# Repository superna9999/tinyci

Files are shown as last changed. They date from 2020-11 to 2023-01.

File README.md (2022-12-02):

# TinyCI

General Concept:

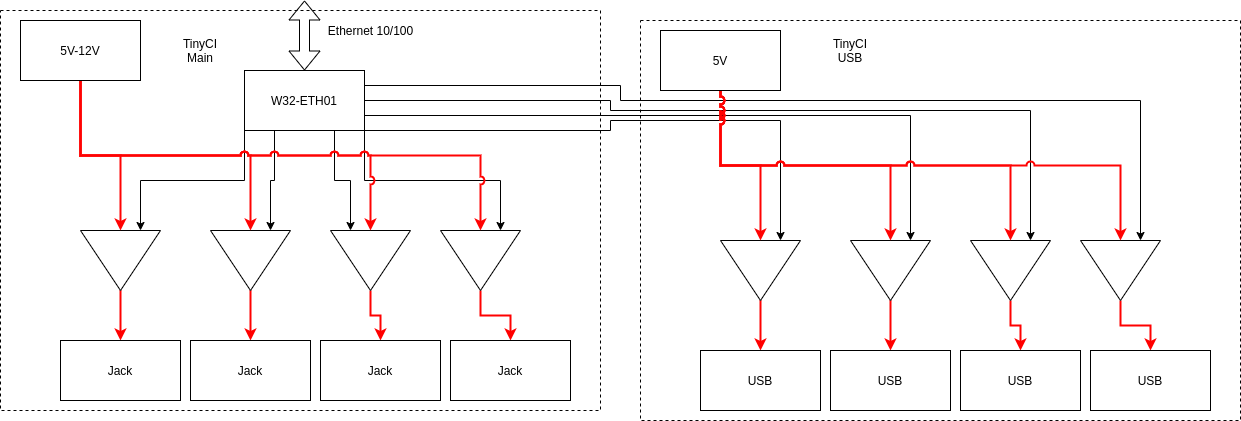
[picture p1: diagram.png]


TinyCi Main
-----------

Relay board controlled by a `W32-ETH01` module.

Input: 5V

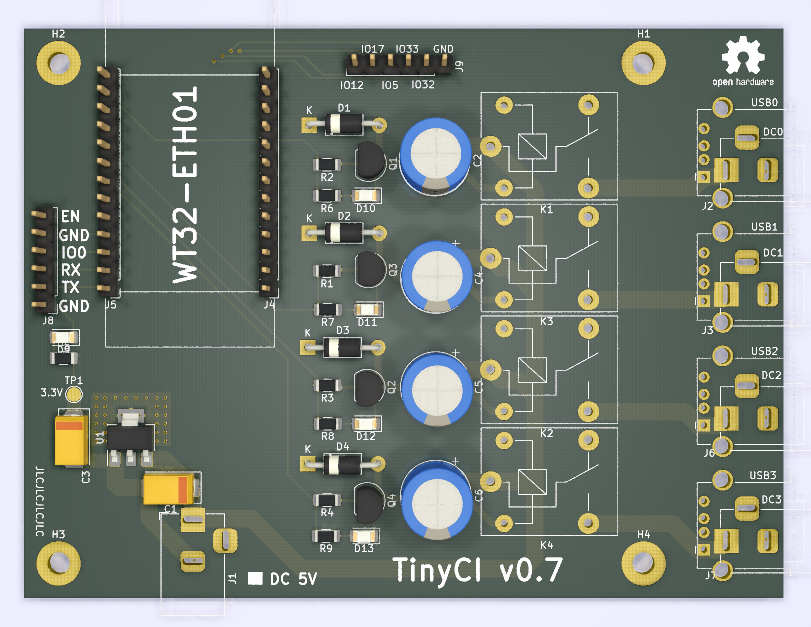
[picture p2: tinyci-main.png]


Produced:
- v0.5: x5 produced, x4 soldered, x3 used in production
- v0.7: x5 produced & used in production
- v0.8: Design done

ESP32 Firmware: see `firmware/tinyci-fw/`

Remote Relay Control script: see `firmware/tinyci-fw/tinyci-relay.py`

TinyCi USB
-----------

Secondary Relay board controlled by the `W32-ETH01` on the main board.

Input: 5V to 12V

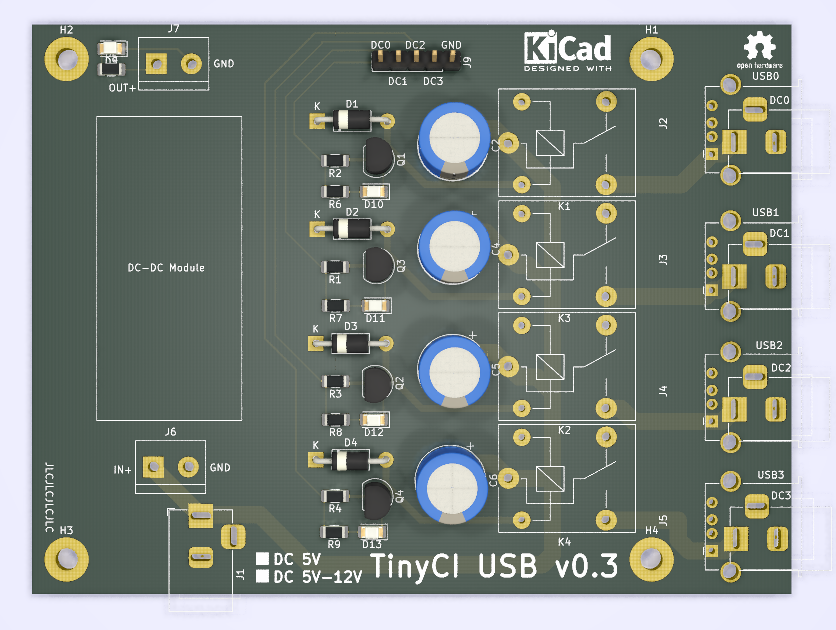
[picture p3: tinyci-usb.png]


Produced:
- v0.1: x5 produced, x3 soldered, x2 used in production
- v0.3: x5 Produced, x0 used in production

TinySerial
-----------

Quad FTDI board + breakout of all FTDI I/Os with the TinyCi form factor + holes
to hook a Pi/LaFrite/LePotato to control the FTDI + TinyCi USBs.

Input: USB

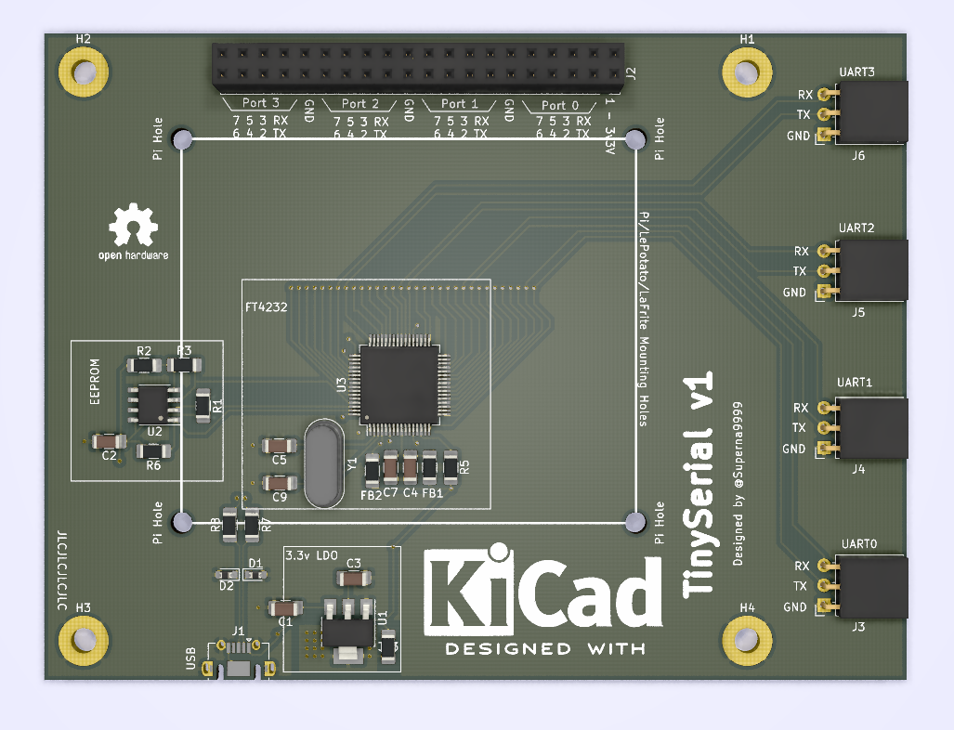
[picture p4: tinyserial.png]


Produced:
- v1: x5 Produced, failed to bringup, will be replaced with OctoSerial using CH348Q

LICENCE
-------

```
CERN OPEN HARDWARE LICENCE v1.1
```

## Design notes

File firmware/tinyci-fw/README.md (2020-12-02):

# TinyCI Relay Firmware

## Build
```
. /path/to/esp-idf/export.sh
idf.py build
```

## Ground IO0
```
idf.py flash
```

## Test
```
python2.7 tinyci-relay.py 192.168.1.12 PWR0
python2.7 tinyci-relay.py 192.168.1.12 OFF2
```

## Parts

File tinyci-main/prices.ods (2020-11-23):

Model | Unit per Cmd | Cmd Number | Total Price | Price per unit | Unit Used | Price for board | Possible num of boards | Url
BC337-25 | 50 | 1 | 1,34 € | 0,03 € | 4 | 0,11 € | 12,5 | https://fr.aliexpress.com/item/33027063943.html
SRD-03 | 5 | 5 | 4,03 € | 0,16 € | 4 | 0,64 € | 6,25 | https://fr.aliexpress.com/item/10000000543749.html
WT32-ETH01 | 1 | 3 | 22,59 € | 7,53 € | 1 | 7,53 € | 3 | https://fr.aliexpress.com/item/1005001556914151.html
AMS1117-3.3 | 10 | 1 | 1,44 € | 0,14 € | 1 | 0,14 € | 10 | https://fr.aliexpress.com/item/4001158893261.html
JACK | 10 | 2 | 2,36 € | 0,12 € | 5 | 0,59 € | 4 | https://fr.aliexpress.com/item/33005175186.html
polyfuse | 100 | 1 | 3,51 € | 0,04 € | 4 | 0,14 € | 25 | https://fr.aliexpress.com/item/32959558358.html
35V 10UF D | 10 | 1 | 1,04 € | 0,10 € | 2 | 0,21 € | 5 | https://fr.aliexpress.com/item/4000190521272.html
1N4001 | 100 | 1 | 1,64 € | 0,02 € | 8 | 0,13 € | 12,5 | https://fr.aliexpress.com/item/32829962185.html
1000uF | 50 | 1 | 3,93 € | 0,08 € | 4 | 0,31 € | 12,5 | https://fr.aliexpress.com/item/32351437821.html
PCB | 5 | 1 | 7,77 € | 1,55 € | 1 | 1,55 € | 5 | https://jlcpcb.com/
LED | 100 | 1 | 1,53 € | 0,02 € | 5 | 0,08 € | 20 | https://www.aliexpress.com/item/33049173418.html
R | 660 | 1 | 2,83 € | 0,00 € | 9 | 0,04 € | 73,3333333333333 | https://www.aliexpress.com/item/33029877427.html
 |  |  |  |  | Board Price | 11,48 €

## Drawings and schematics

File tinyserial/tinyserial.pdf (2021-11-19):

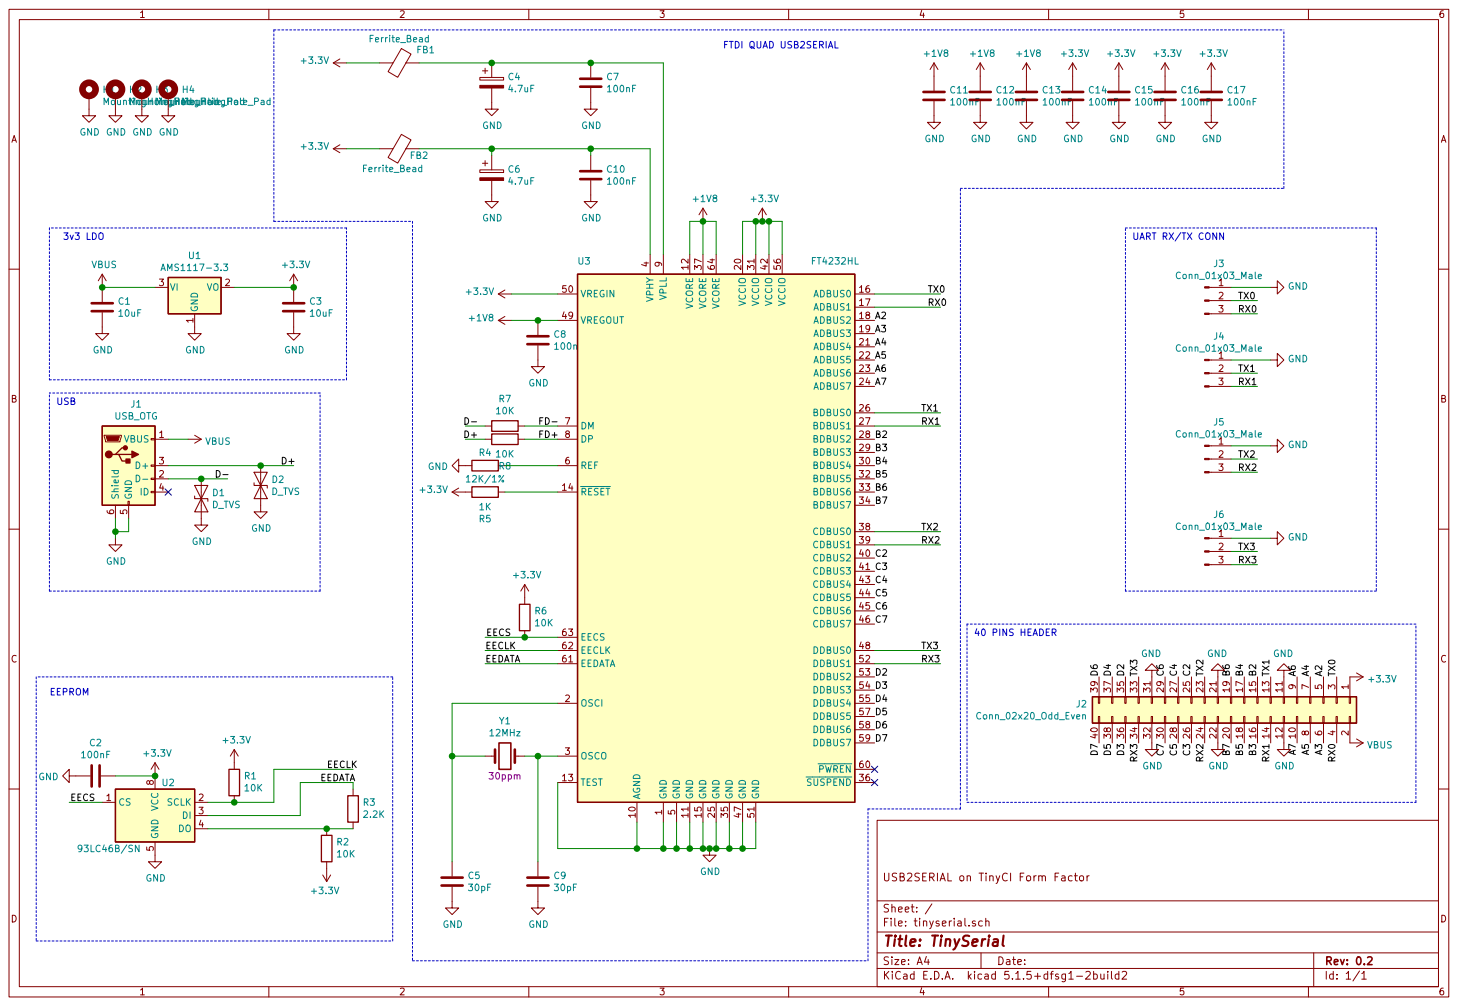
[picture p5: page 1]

5 VREGIN 50 GND 51 DDBUS1 52 DDBUS2 53 DDBUS3 54 DDBUS4 55 VCCIO 56 DDBUS5 57 DDBUS6 58 DDBUS7 59 REF 6 PWREN 60 EEDATA 61 EECLK 62 EECS 63 VCORE 64 DM 7 DP 8 VPLL U3 9FT4232HL R5

1 AGND 10 GND 11 VCORE 12 TEST 13 RESET 14 GND 15 ADBUS0 16 ADBUS1 17 ADBUS2 18 ADBUS3 19 OSCI 2 VCCIO 20 ADBUS4 21 ADBUS5 22 ADBUS6 23 ADBUS7 24 GND 25 BDBUS0 26 BDBUS1 27 BDBUS2 28 BDBUS3 29 OSCO 3 BDBUS4 30 VCCIO 31 BDBUS5 32 BDBUS6 33 BDBUS7 34 GND 35 SUSPEND 36 VCORE 37 CDBUS0 38 CDBUS1 39 VPHY

4 CDBUS2 40 CDBUS3 41 VCCIO 42 CDBUS4 43 CDBUS5 44 CDBUS6 45 CDBUS7 46 GND 47 DDBUS0 48 VREGOUT 49 GND

File: tinyserial.sch Sheet: / USB2SERIAL on TinyCI Form Factor

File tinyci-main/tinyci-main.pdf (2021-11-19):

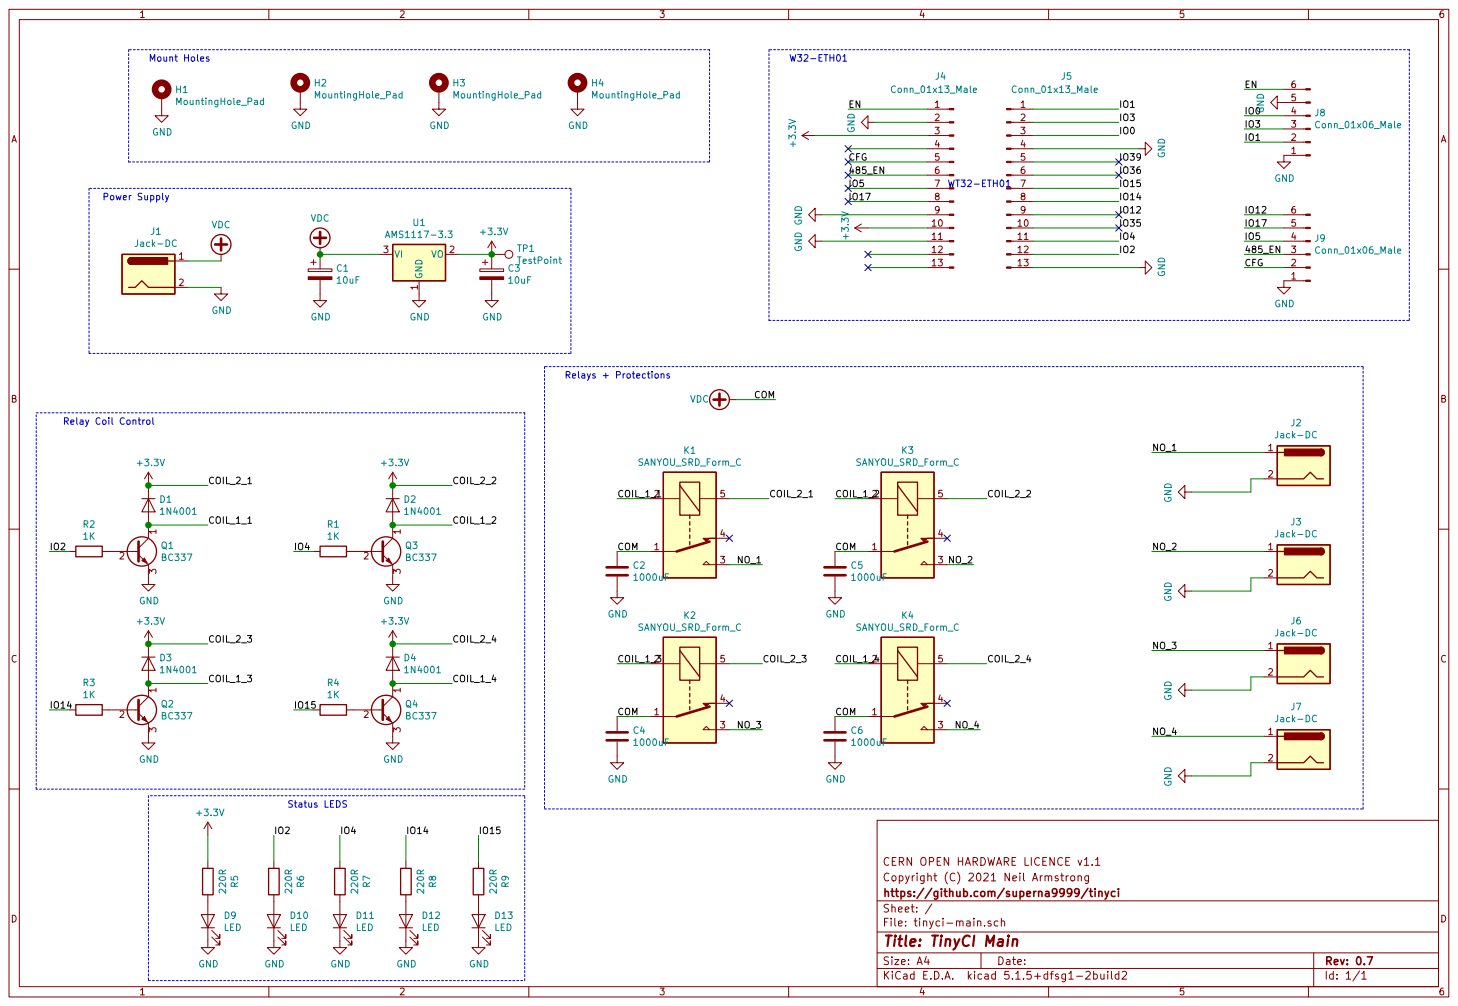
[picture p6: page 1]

Mount Holes Power Supply

Copyright (C) 2021 Neil Armstrong CERN OPEN HARDWARE LICENCE v1.1 GND
5 K2 SANYOU_SRD_Form_C

File: tinyci-main.sch Sheet: / https://github.com/superna9999/tinyci

Id: 1/1 Title: TinyCI Main

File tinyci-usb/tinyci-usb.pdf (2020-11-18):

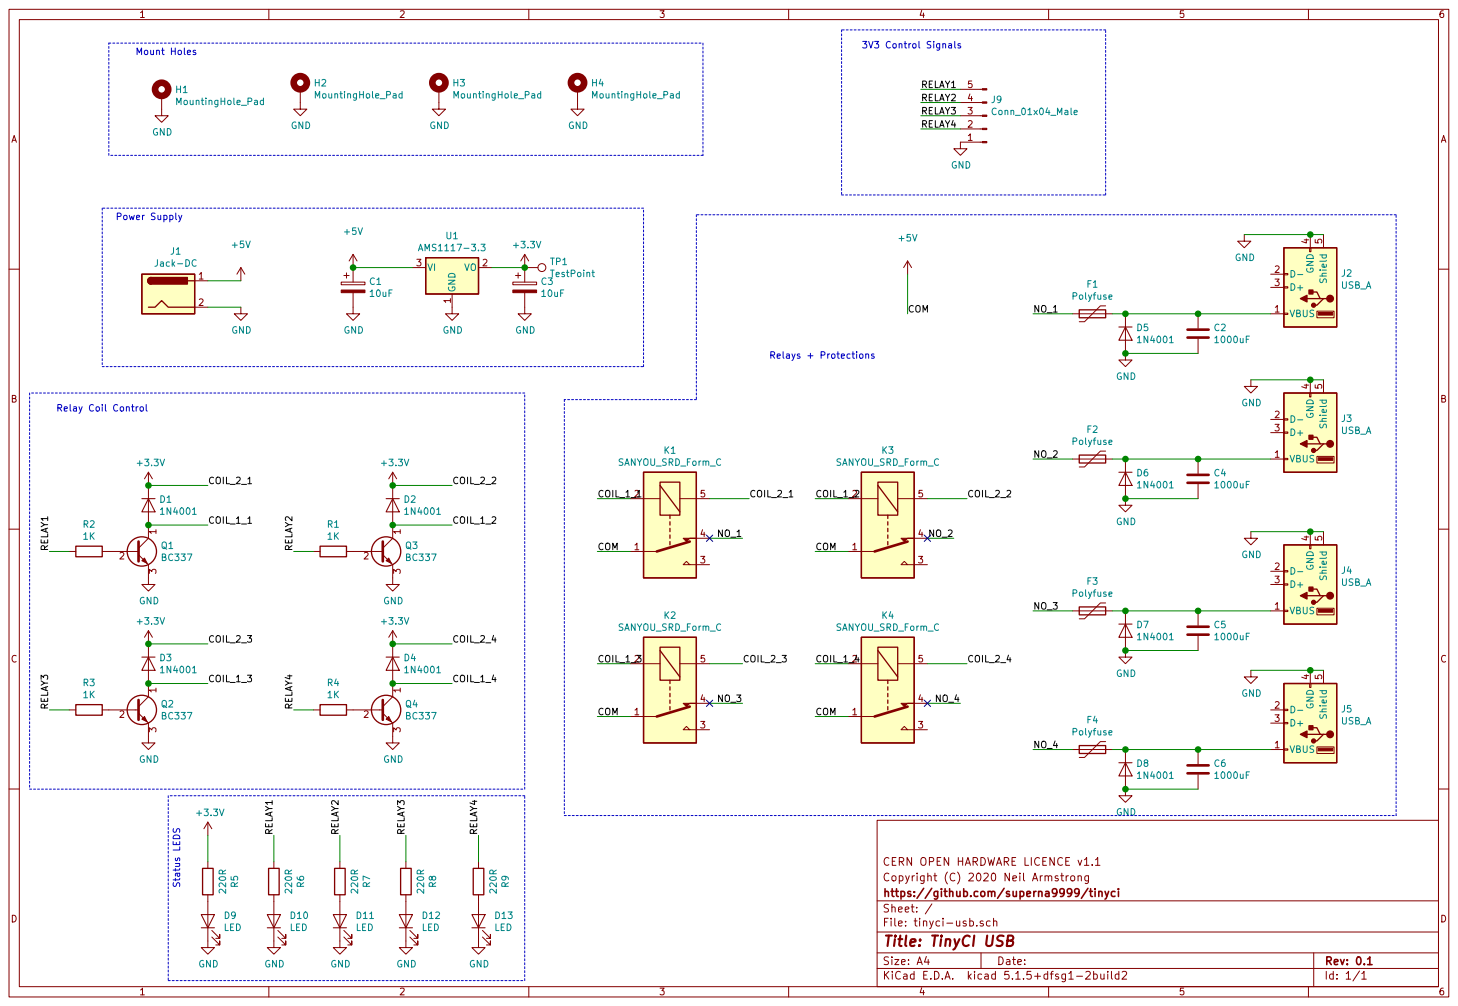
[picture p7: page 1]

3V3 Control Signals Mount Holes Power Supply

File: tinyci-usb.sch Sheet: / https://github.com/superna9999/tinyci

Id: 1/1 Title: TinyCI USB

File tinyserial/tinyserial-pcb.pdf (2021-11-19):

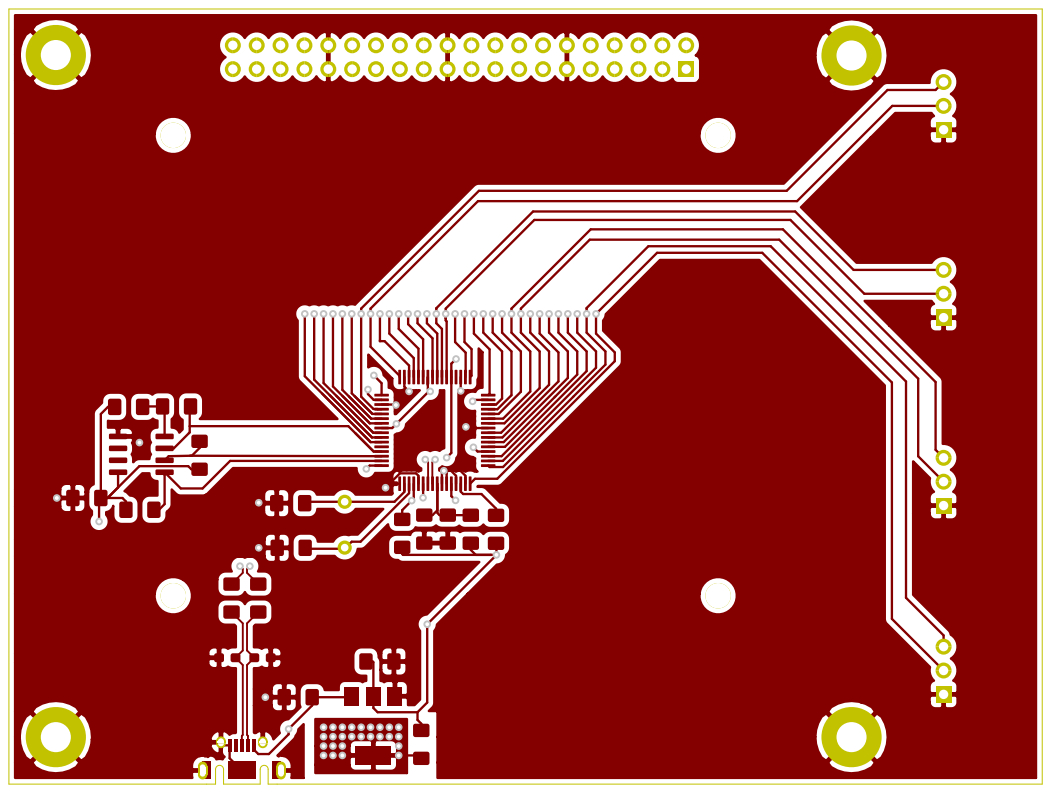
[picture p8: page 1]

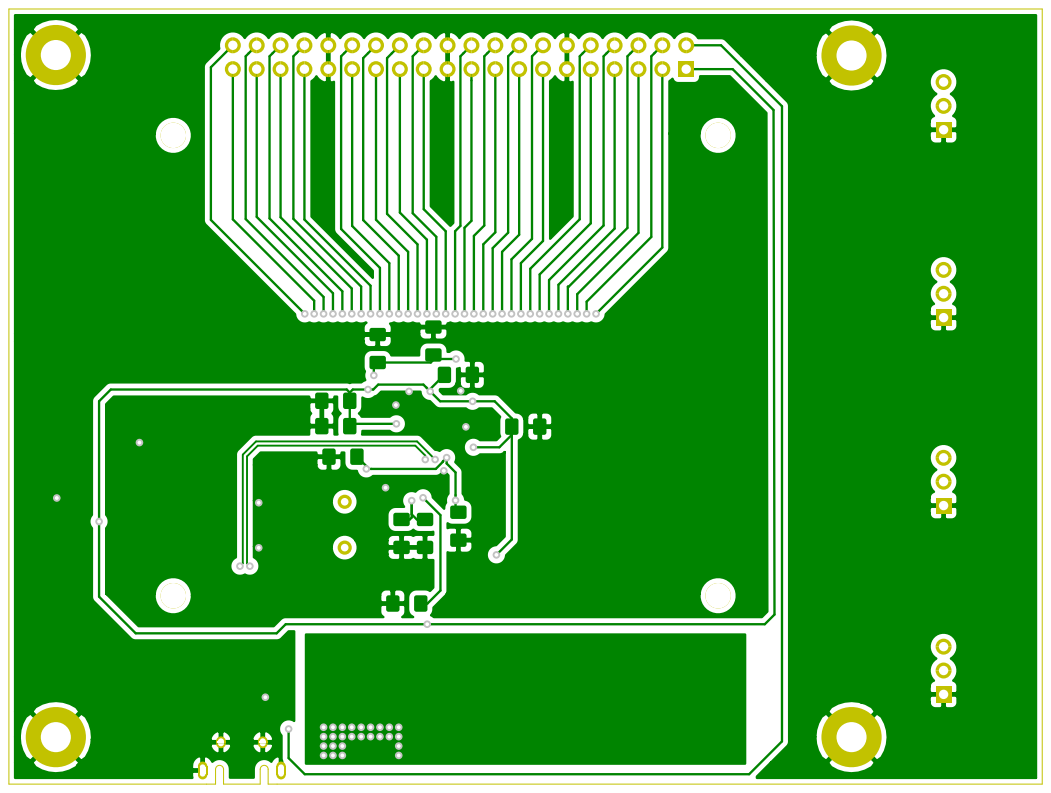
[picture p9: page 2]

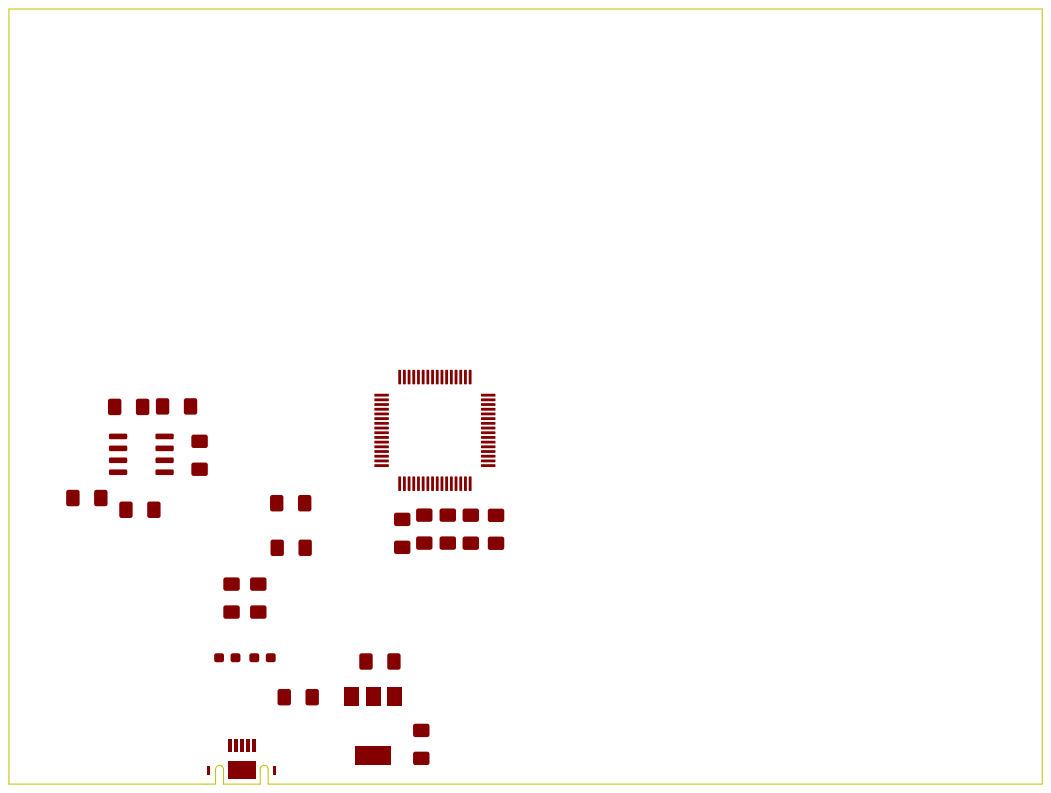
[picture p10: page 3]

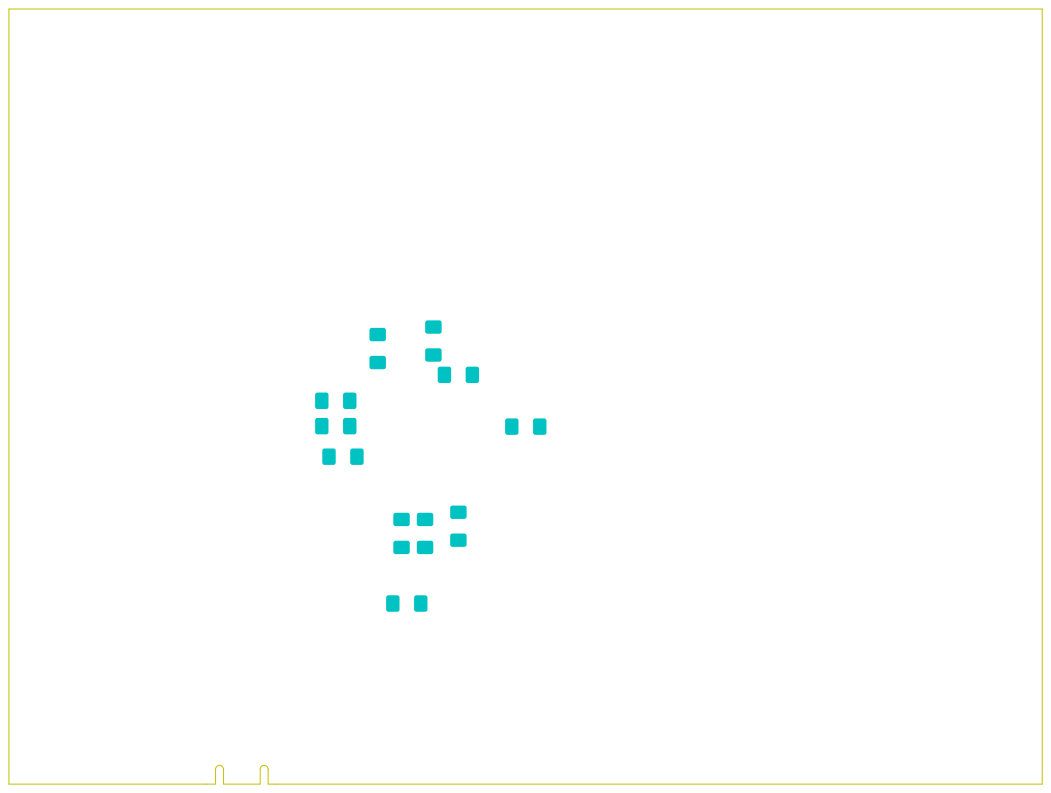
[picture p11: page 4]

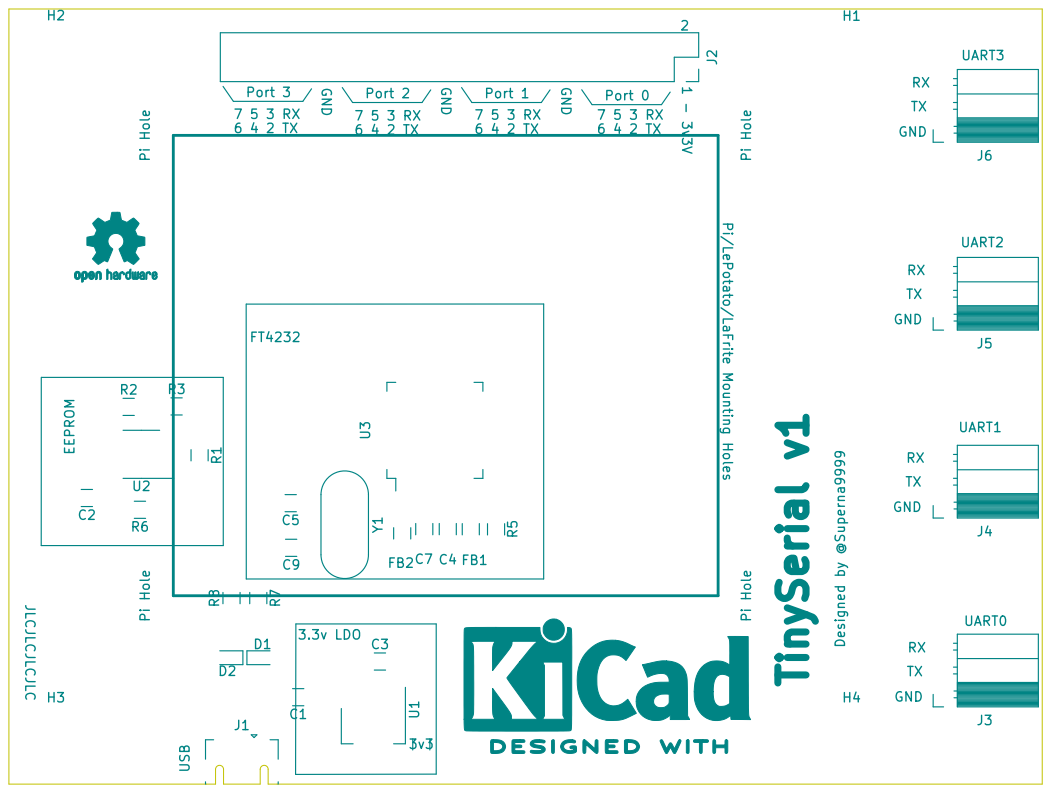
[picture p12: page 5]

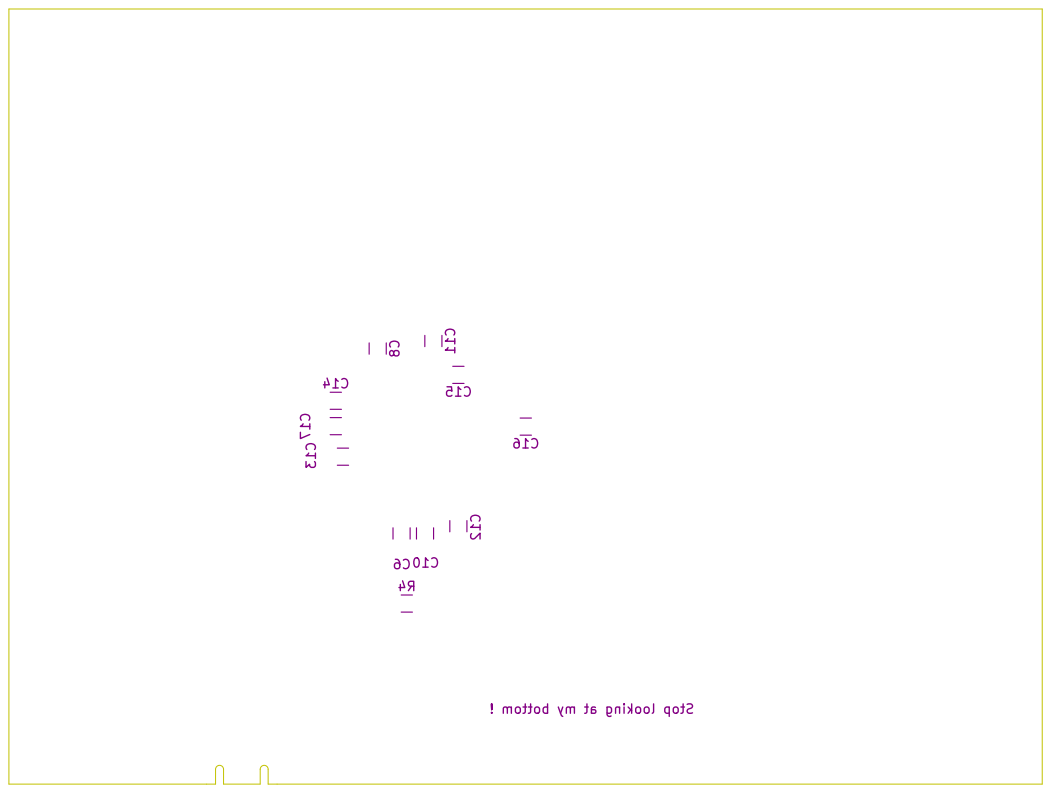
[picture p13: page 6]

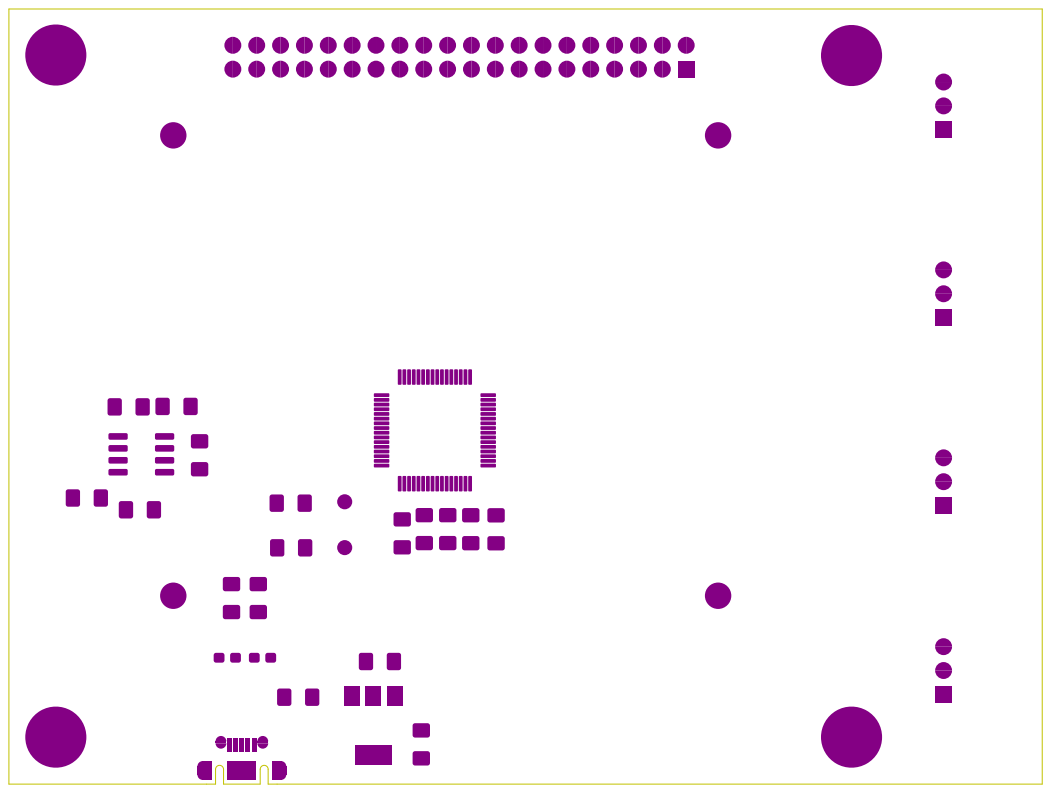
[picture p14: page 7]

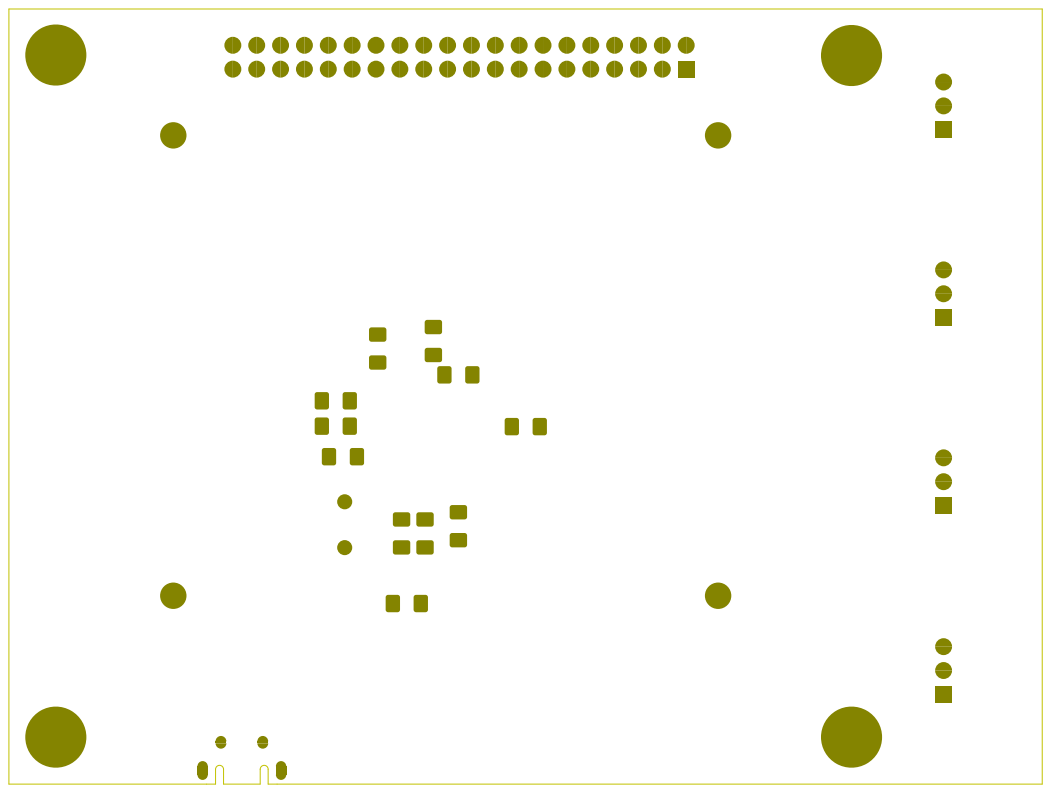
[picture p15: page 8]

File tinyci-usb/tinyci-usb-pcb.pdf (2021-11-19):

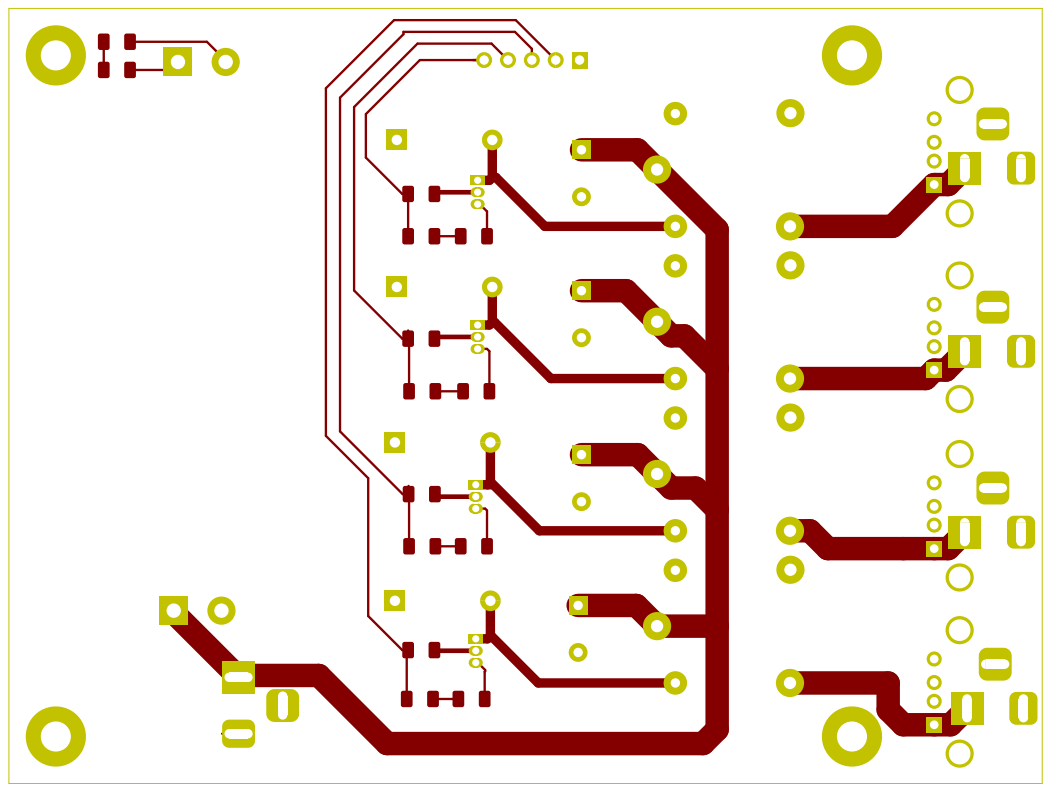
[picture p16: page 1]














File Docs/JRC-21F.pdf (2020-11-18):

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

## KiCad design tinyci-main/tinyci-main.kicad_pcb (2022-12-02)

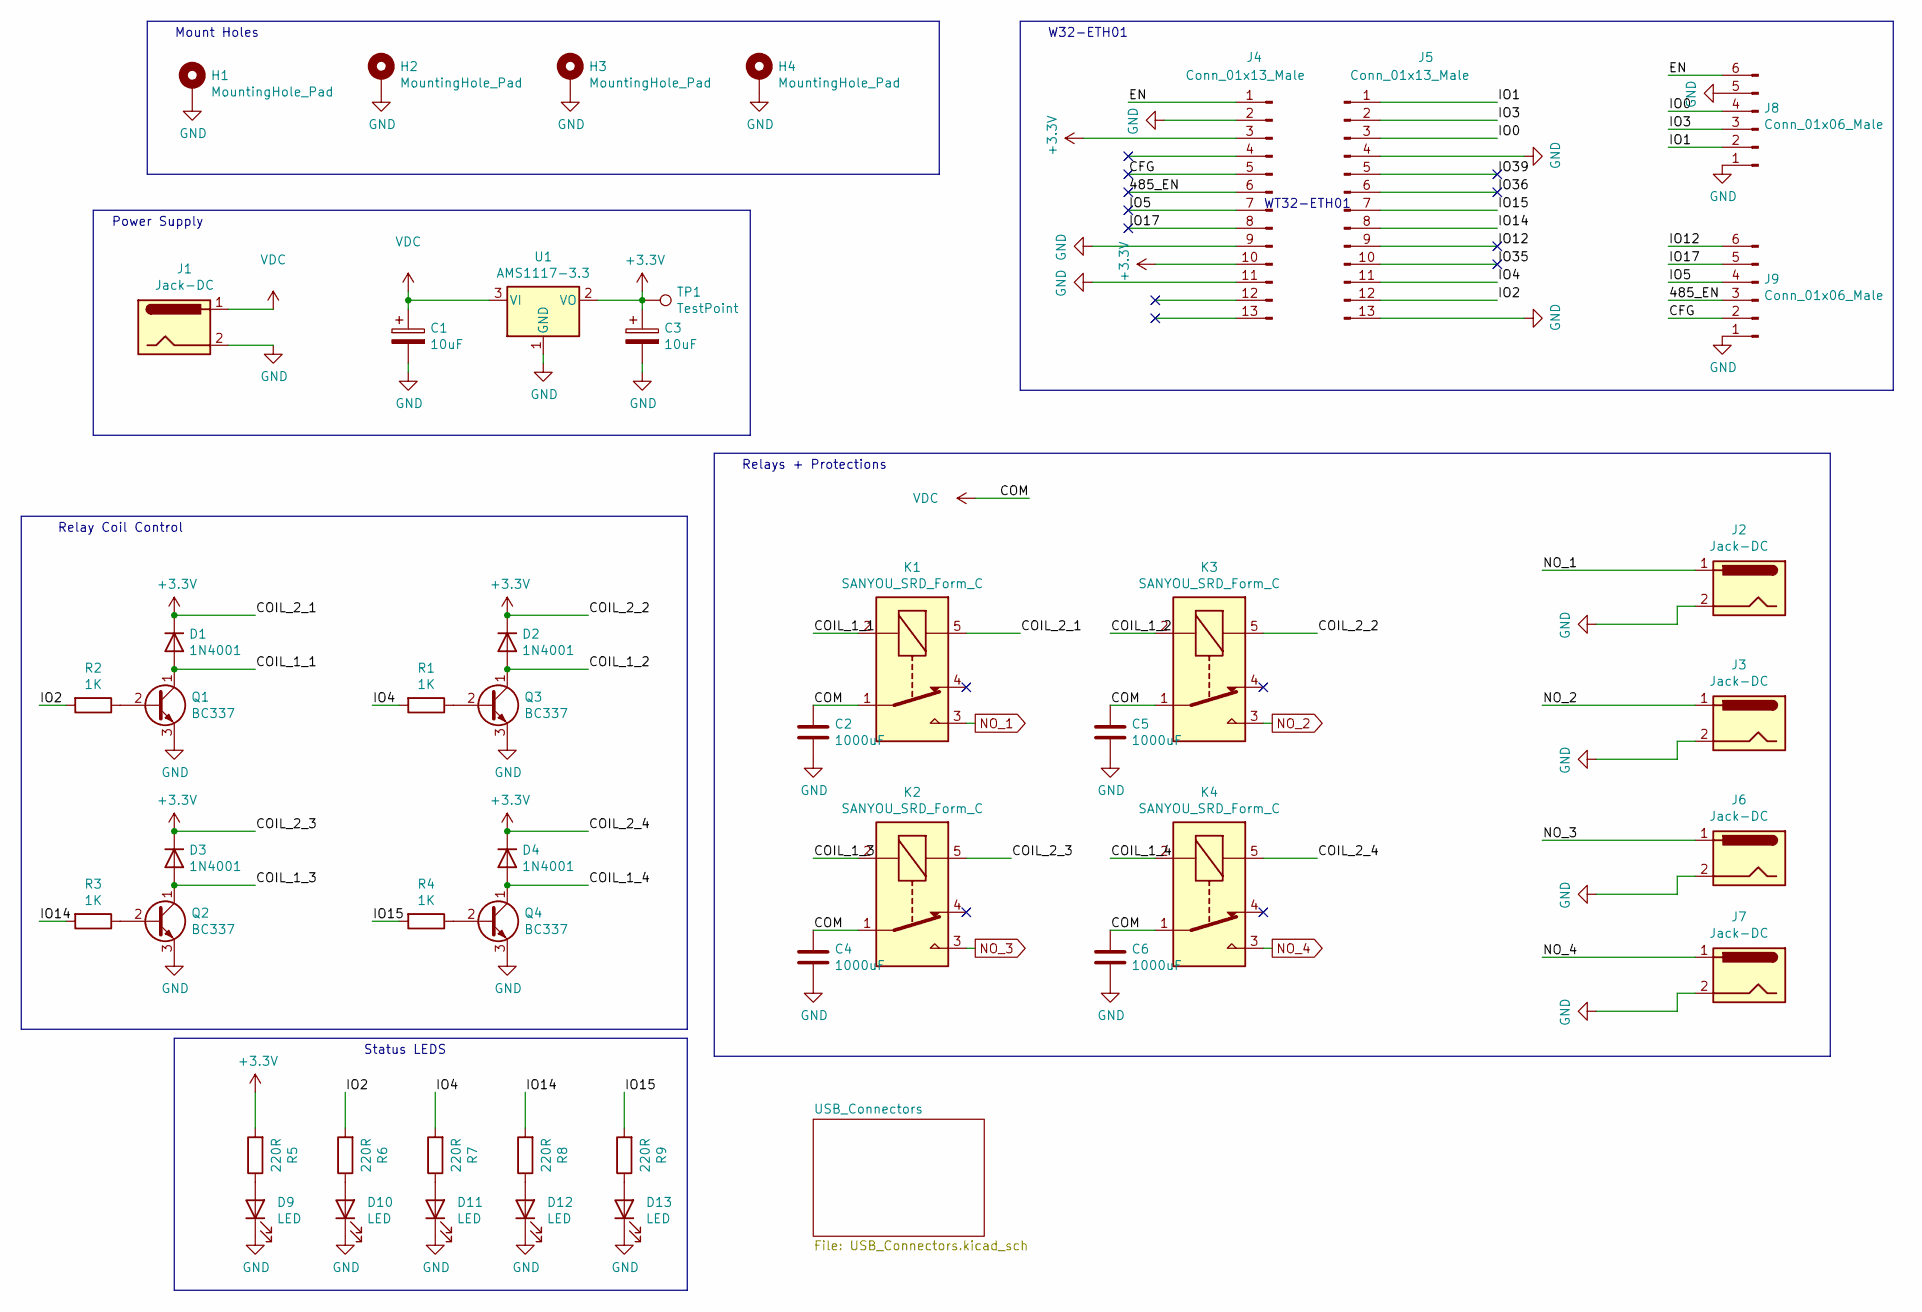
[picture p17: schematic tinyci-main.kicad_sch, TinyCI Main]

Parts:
C1, C3: 10uF; CP_EIA-7343-31_Kemet-D
C2, C4, C5, C6: 1000uF; CP_Radial_D10.0mm_P5.00mm
D1, D2, D3, D4: 1N4001; D_DO-41_SOD81_P10.16mm_Horizontal
D9, D10, D11, D12, D13: LED; LED_1206_3216Metric
H1, H2, H3, H4: MountingHole_Pad; MountingHole_3.2mm_M3_Pad
J1, J2, J3, J6, J7: Jack-DC; BarrelJack_Horizontal
J4, J5: Conn_01x13_Male; PinHeader_1x13_P2.54mm_Vertical
J8, J9: Conn_01x06_Male; PinHeader_1x06_P2.54mm_Vertical
K1, K2, K3, K4: SANYOU_SRD_Form_C; Relay_SPDT_SANYOU_SRD_Series_Form_C
Q1, Q2, Q3, Q4: BC337; TO-92_Inline
R1, R2, R3, R4: 1K; R_1206_3216Metric
R5, R6, R7, R8, R9: 220R; R_1206_3216Metric
TP1: TestPoint; TestPoint_Pad_D2.0mm
U1: AMS1117-3.3; SOT-223-3_TabPin2

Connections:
+3.3V: C3.1, D1.1 (K), D2.1 (K), D3.1 (K), D4.1 (K), J4.3, J4.10, K1.5, K2.5, K3.5, K4.5, R5.2, TP1.1, U1.2 (VO)
/485_EN: J4.6, J9.3
/CFG: J4.5, J9.2
/COIL_1_1: D1.2 (A), K1.2, Q1.1 (C)
/COIL_1_2: D2.2 (A), K3.2, Q3.1 (C)
/COIL_1_3: D3.2 (A), K2.2, Q2.1 (C)
/COIL_1_4: D4.2 (A), K4.2, Q4.1 (C)
/EN: J4.1, J8.6
/IO0: J5.3, J8.4
/IO1: J5.1, J8.2
/IO2: J5.12, R2.2, R6.2
/IO3: J5.2, J8.3
/IO4: J5.11, R1.2, R7.2
/IO5: J4.7, J9.4
/IO12: J5.9, J9.6
/IO14: J5.8, R3.2, R8.2
/IO15: J5.7, R4.2, R9.2
/IO17: J4.8, J9.5
/IO35: J5.10
/IO36: J5.6
/IO39: J5.5
GND: C1.2, C2.2, C3.2, C4.2, C5.2, C6.2, D9.1 (K), D10.1 (K), D11.1 (K), D12.1 (K), D13.1 (K), H1.1, H2.1, H3.1, H4.1, J1.2, J2.2, J3.2, J4.2, J4.9, J4.11, J5.4, J5.13, J6.2, J7.2, J8.1, J8.5, J9.1, Q1.3 (E), Q2.3 (E), Q3.3 (E), Q4.3 (E), U1.1 (GND); also elsewhere on the board
NO_1: J2.1, K1.3; also elsewhere on the board
NO_2: J3.1, K3.3; also elsewhere on the board
NO_3: J6.1, K2.3; also elsewhere on the board
NO_4: J7.1, K4.3; also elsewhere on the board
unnamed: D9.2 (A), R5.1
unnamed: D10.2 (A), R6.1
unnamed: D11.2 (A), R7.1
unnamed: D12.2 (A), R8.1
unnamed: D13.2 (A), R9.1
unnamed: Q1.2 (B), R2.1
unnamed: Q2.2 (B), R3.1
unnamed: Q3.2 (B), R1.1
unnamed: Q4.2 (B), R4.1
VDC: C1.1, C2.1, C4.1, C5.1, C6.1, J1.1, K1.1, K2.1, K3.1, K4.1, U1.3 (VI)

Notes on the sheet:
Status LEDS
Power Supply
W32-ETH01
Mount Holes
Relays + Protections
Relay Coil Control
WT32-ETH01

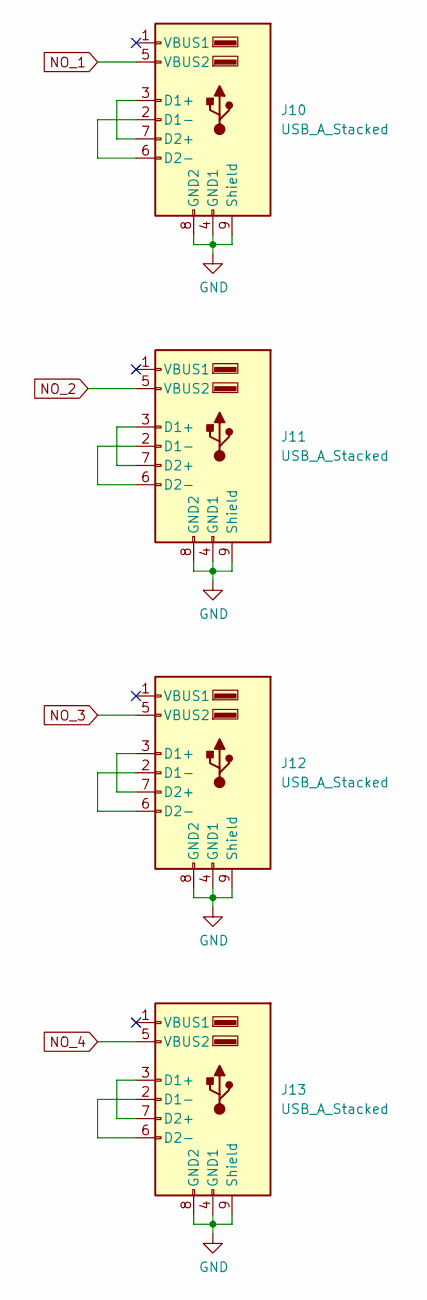
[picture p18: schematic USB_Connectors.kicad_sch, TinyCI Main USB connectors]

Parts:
J10, J11, J12, J13: USB_A_Stacked

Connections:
GND: J10.4 (GND1), J10.8 (GND2), J10.9 (Shield), J11.4 (GND1), J11.8 (GND2), J11.9 (Shield), J12.4 (GND1), J12.8 (GND2), J12.9 (Shield), J13.4 (GND1), J13.8 (GND2), J13.9 (Shield); also elsewhere on the board
NO_1: J10.5 (VBUS2); also elsewhere on the board
NO_2: J11.5 (VBUS2); also elsewhere on the board
NO_3: J12.5 (VBUS2); also elsewhere on the board
NO_4: J13.5 (VBUS2); also elsewhere on the board
unnamed: J10.2 (D1-), J10.6 (D2-)
unnamed: J10.3 (D1+), J10.7 (D2+)
unnamed: J11.2 (D1-), J11.6 (D2-)
unnamed: J11.3 (D1+), J11.7 (D2+)
unnamed: J12.2 (D1-), J12.6 (D2-)
unnamed: J12.3 (D1+), J12.7 (D2+)
unnamed: J13.2 (D1-), J13.6 (D2-)
unnamed: J13.3 (D1+), J13.7 (D2+)

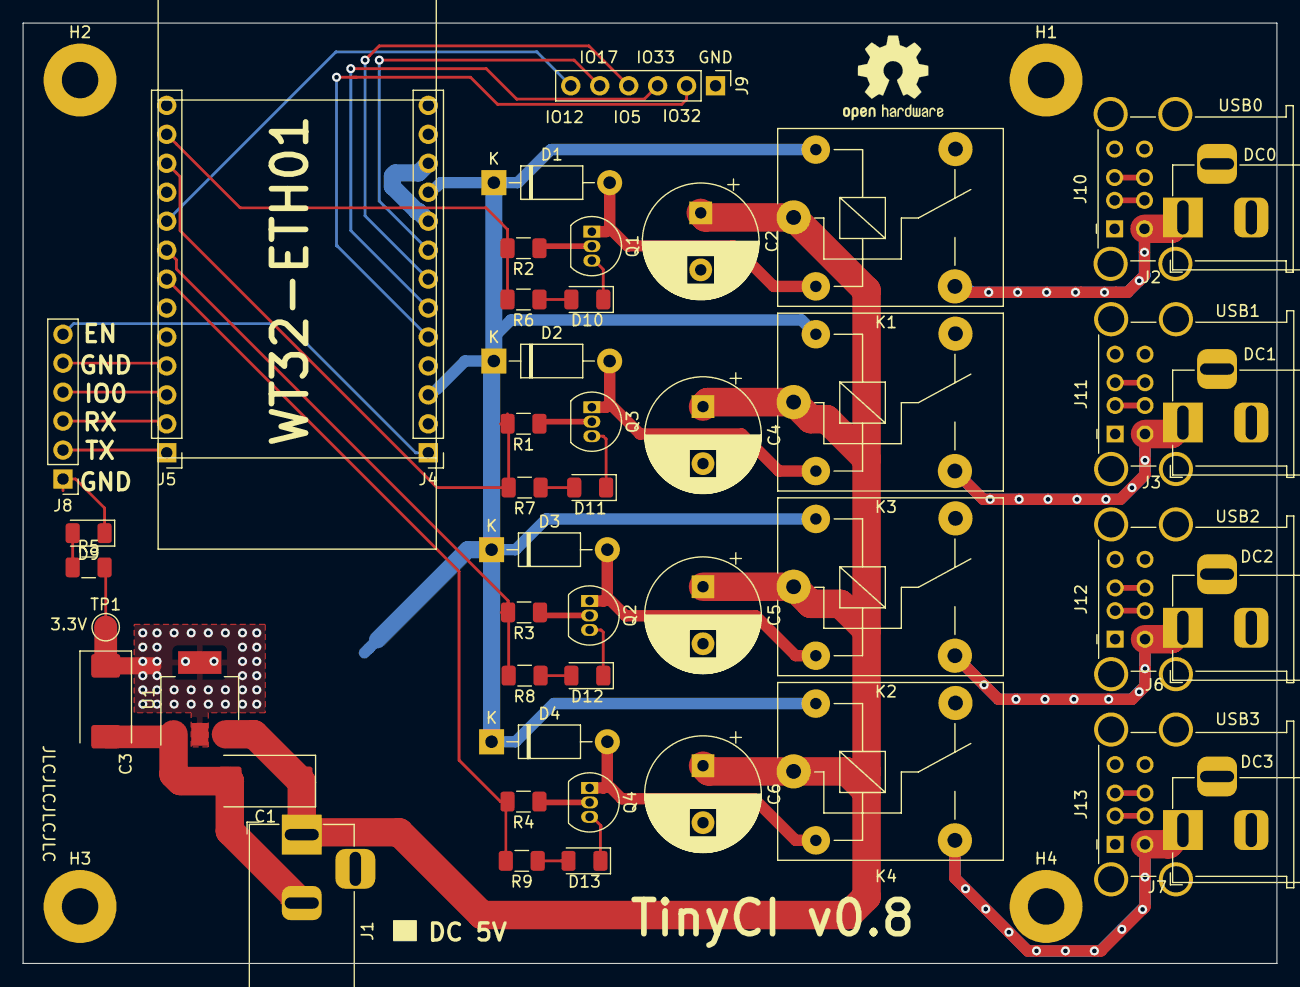
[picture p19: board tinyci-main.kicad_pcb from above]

Board: 2 copper layers, 110.0 x 82.5 mm, 51 parts (0 on the bottom side), 41 nets.

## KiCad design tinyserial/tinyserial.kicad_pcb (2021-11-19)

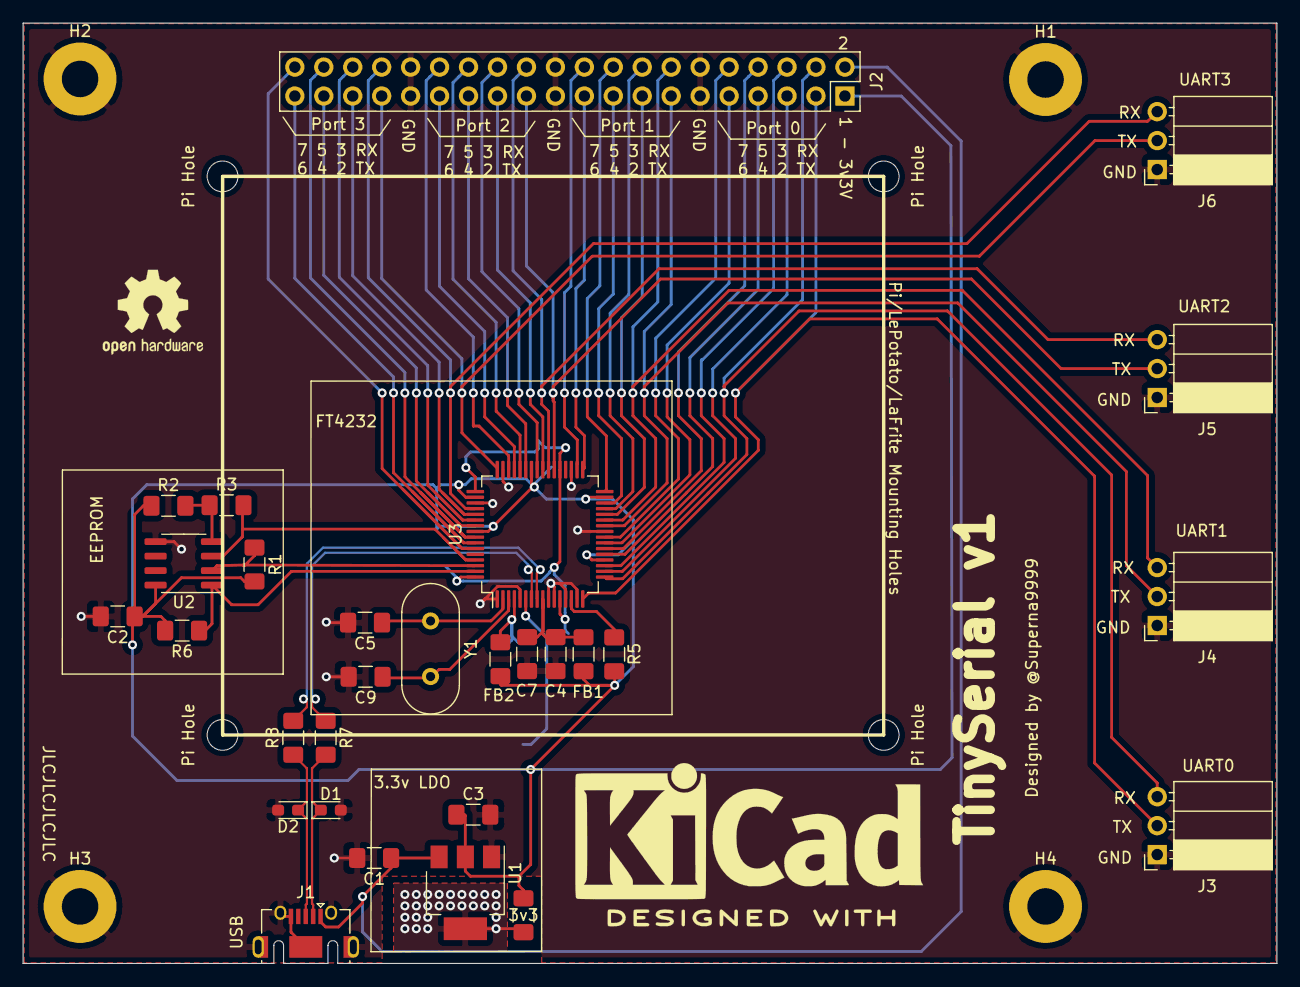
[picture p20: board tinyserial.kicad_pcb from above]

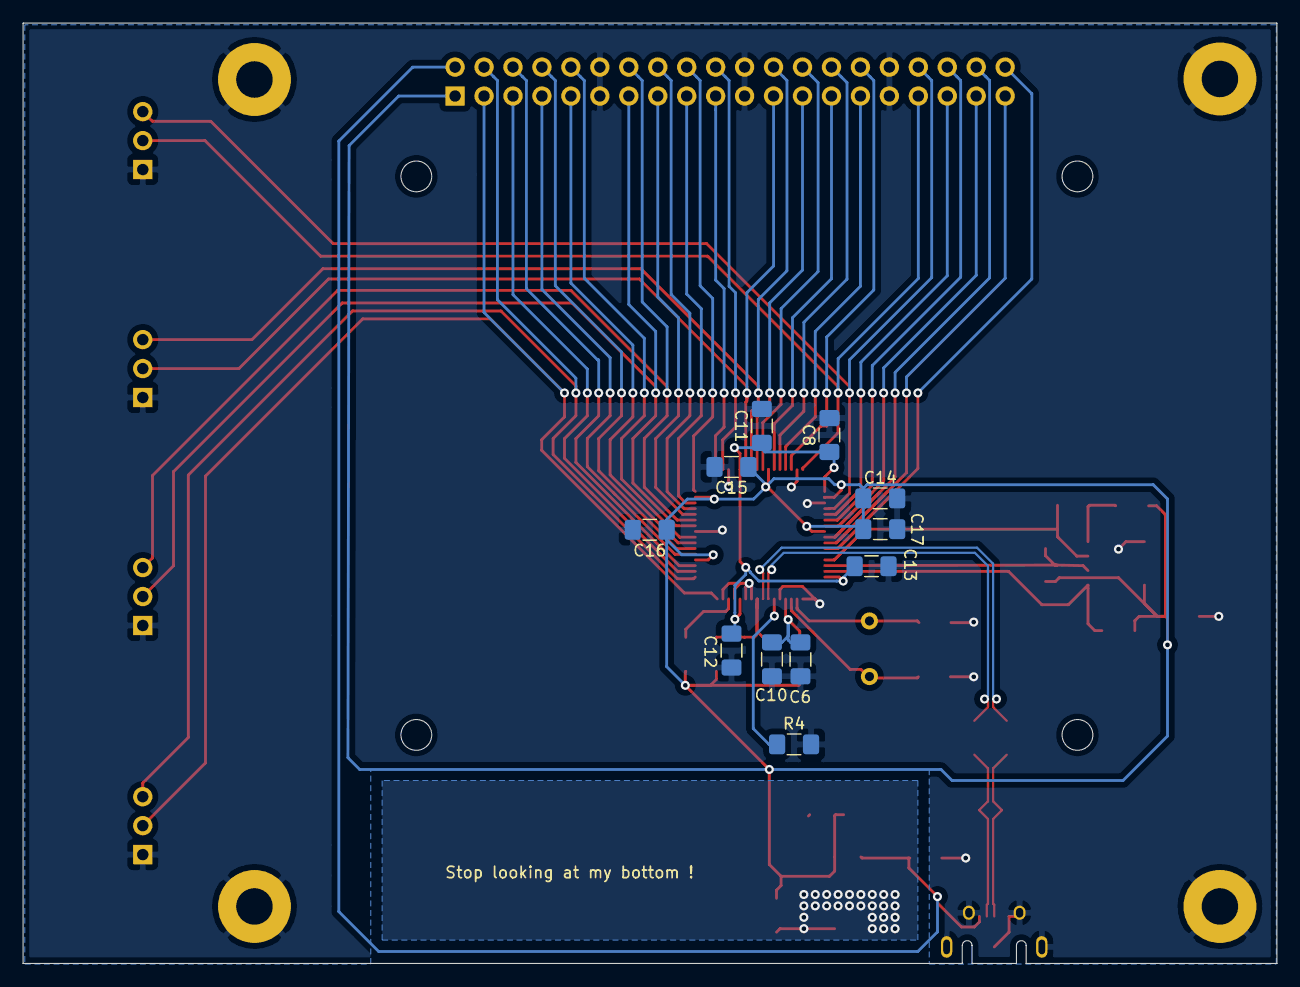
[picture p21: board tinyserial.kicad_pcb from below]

Board: 2 copper layers, 110.0 x 82.5 mm, 47 parts (11 on the bottom side), 50 nets.

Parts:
C1, C3: 10uF; C_1206_3216Metric_Pad1.42x1.75mm_HandSolder
C2, C7, C8, C10, C11, C12, C13, C14, C15, C16, C17: 100nF; C_1206_3216Metric_Pad1.42x1.75mm_HandSolder
C4, C6: 4.7uF; C_1206_3216Metric_Pad1.42x1.75mm_HandSolder
C5, C9: 30pF; C_1206_3216Metric_Pad1.42x1.75mm_HandSolder
D1, D2: D_TVS; D_0603_1608Metric_Pad1.05x0.95mm_HandSolder
FB1, FB2: Ferrite_Bead; R_1206_3216Metric_Pad1.42x1.75mm_HandSolder
H1, H2, H3, H4: MountingHole_Pad; MountingHole_3.2mm_M3_Pad
J1: USB_OTG; USB_Micro-AB_Molex_47590-0001
J2: Conn_02x20_Odd_Even; PinSocket_2x20_P2.54mm_Vertical
J3, J4, J5, J6: Conn_01x03_Male; PinSocket_1x03_P2.54mm_Horizontal
Pi Hole: MountingHole_2.7mm_M2.5
Pi Hole#2, Pi Hole#3, Pi Hole#4: MountingHole_2.7mm_M2.5
R1, R2, R6, R7, R8: 10K; R_1206_3216Metric_Pad1.42x1.75mm_HandSolder
R3: 2.2K; R_1206_3216Metric_Pad1.42x1.75mm_HandSolder
R4: 12K/1%; R_1206_3216Metric_Pad1.42x1.75mm_HandSolder
R5: 1K; R_1206_3216Metric_Pad1.42x1.75mm_HandSolder
U1: AMS1117-3.3; SOT-223-3_TabPin2
U2: 93LC46B/SN; SOIC-8_3.9x4.9mm_P1.27mm
U3: FT4232HL; LQFP-64_10x10mm_P0.5mm
Y1: 12MHz; Crystal_HC49-4H_Vertical

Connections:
+1V8: C8.1, C11.1, C12.1, C13.1, U3.12, U3.37, U3.49, U3.64
+3V3: C2.1, C3.1, C14.1, C15.1, C16.1, C17.1, FB1.2, FB2.2, J2.1, R1.2, R2.1, R5.1, R6.2, U1.2, U2.8, U3.20, U3.31, U3.42, U3.50, U3.56
/A2: J2.5, U3.18
/A3: J2.6, U3.19
/A4: J2.7, U3.21
/A5: J2.8, U3.22
/A6: J2.9, U3.23
/A7: J2.10, U3.24
/B2: J2.15, U3.28
/B3: J2.16, U3.29
/B4: J2.17, U3.30
/B5: J2.18, U3.32
/B6: J2.19, U3.33
/B7: J2.20, U3.34
/C2: J2.25, U3.40
/C3: J2.26, U3.41
/C4: J2.27, U3.43
/C5: J2.28, U3.44
/C6: J2.29, U3.45
/C7: J2.30, U3.46
/D2: J2.35, U3.53
/D3: J2.36, U3.54
/D4: J2.37, U3.55
/D5: J2.38, U3.57
/D6: J2.39, U3.58
/D7: J2.40, U3.59
/D+: D2.1, J1.3, R8.1
/D-: D1.1, J1.2, R7.2
/EECLK: R1.1, U2.2, U3.62
/EECS: R6.1, U2.1, U3.63
/EEDATA: R3.2, U2.3, U3.61
/FD+: R8.2, U3.8
/FD-: R7.1, U3.7
/RX0: J2.4, J3.3, U3.17
/RX1: J2.14, J4.3, U3.27
/RX2: J2.24, J5.3, U3.39
/RX3: J2.34, J6.3, U3.52
/TX0: J2.3, J3.2, U3.16
/TX1: J2.13, J4.2, U3.26
/TX2: J2.23, J5.2, U3.38
/TX3: J2.33, J6.2, U3.48
GND: C1.2, C2.2, C3.2, C4.2, C5.2, C6.2, C7.2, C8.2, C9.2, C10.2, C11.2, C12.2, C13.2, C14.2, C15.2, C16.2, C17.2, D1.2, D2.2, H1.1, H2.1, H3.1, H4.1, J1.5, J1.6, J2.11, J2.12, J2.21, J2.22, J2.31, J2.32, J3.1, J4.1, J5.1, J6.1, R4.2, U1.1, U2.5, U3.1, U3.5, U3.10, U3.11, U3.13, U3.15, U3.25, U3.35, U3.47, U3.51
unnamed: C4.1, C7.1, FB1.1, U3.9
unnamed: C5.1, U3.2, Y1.1
unnamed: C9.1, U3.3, Y1.2
unnamed: C6.1, C10.1, FB2.1, U3.4
unnamed: R2.2, R3.1, U2.4
unnamed: R4.1, U3.6
unnamed: R5.2, U3.14
VBUS: C1.1, J1.1, J2.2, U1.3

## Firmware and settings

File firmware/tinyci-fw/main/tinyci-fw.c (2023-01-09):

/* Ethernet Basic Example

   This example code is in the Public Domain (or CC0 licensed, at your option.)

   Unless required by applicable law or agreed to in writing, this
   software is distributed on an "AS IS" BASIS, WITHOUT WARRANTIES OR
   CONDITIONS OF ANY KIND, either express or implied.
*/
#include <stdio.h>
#include <string.h>
#include "freertos/FreeRTOS.h"
#include "freertos/task.h"
#include "esp_netif.h"
#include "esp_eth.h"
#include "esp_event.h"
#include "esp_log.h"
#include "driver/gpio.h"
#include "sdkconfig.h"
#include "lwip/err.h"
#include "lwip/sockets.h"
#include "lwip/sys.h"
#include <lwip/netdb.h>

static const char *TAG = "tinyci-fw";

#define ETH_MDC_GPIO		23
#define ETH_MDIO_GPIO		18
#define ETH_PHY_RST_GPIO	16
#define ETH_PHY_ADDR 		1

/** Event handler for Ethernet events */
static void eth_event_handler(void *arg, esp_event_base_t event_base,
                              int32_t event_id, void *event_data)
{
    uint8_t mac_addr[6] = {0};
    /* we can get the ethernet driver handle from event data */
    esp_eth_handle_t eth_handle = *(esp_eth_handle_t *)event_data;

    switch (event_id) {
    case ETHERNET_EVENT_CONNECTED:
        esp_eth_ioctl(eth_handle, ETH_CMD_G_MAC_ADDR, mac_addr);
        ESP_LOGI(TAG, "Ethernet Link Up");
        ESP_LOGI(TAG, "Ethernet HW Addr %02x:%02x:%02x:%02x:%02x:%02x",
                 mac_addr[0], mac_addr[1], mac_addr[2], mac_addr[3], mac_addr[4], mac_addr[5]);
        break;
    case ETHERNET_EVENT_DISCONNECTED:
        ESP_LOGI(TAG, "Ethernet Link Down");
        break;
    case ETHERNET_EVENT_START:
        ESP_LOGI(TAG, "Ethernet Started");
        break;
    case ETHERNET_EVENT_STOP:
        ESP_LOGI(TAG, "Ethernet Stopped");
        break;
    default:
        break;
    }
}

/** Event handler for IP_EVENT_ETH_GOT_IP */
static void got_ip_event_handler(void *arg, esp_event_base_t event_base,
                                 int32_t event_id, void *event_data)
{
    ip_event_got_ip_t *event = (ip_event_got_ip_t *) event_data;
    const esp_netif_ip_info_t *ip_info = &event->ip_info;

    ESP_LOGI(TAG, "Ethernet Got IP Address");
    ESP_LOGI(TAG, "~~~~~~~~~~~");
    ESP_LOGI(TAG, "ETHIP:" IPSTR, IP2STR(&ip_info->ip));
    ESP_LOGI(TAG, "ETHMASK:" IPSTR, IP2STR(&ip_info->netmask));
    ESP_LOGI(TAG, "ETHGW:" IPSTR, IP2STR(&ip_info->gw));
    ESP_LOGI(TAG, "~~~~~~~~~~~");
}

#define NUM_RELAYS	4

static unsigned int relays_gpio_map[NUM_RELAYS] = {
	[0] = 2,
	[1] = 4,
	[2] = 14,
	[3] = 15,
};

static void reply_str(int sock, struct sockaddr_in6 *source_addr, bool ok)
{
	char nok_reply[4] = "NOK";
	char *reply = nok_reply;

	if (ok)
		reply = &nok_reply[1];

	int err = sendto(sock, reply, strlen(reply)+1, 0, (struct sockaddr *)source_addr, sizeof(*source_addr));
	if (err < 0)
		ESP_LOGE(TAG, "Error occurred during sending: errno %d", errno);
}

static bool relay_ctrl(char *cmd)
{
	unsigned int num = cmd[3] - '0';
	bool enable = false;

	if (!strncmp(cmd, "PWR", 3))
		enable = true;

	if (num >= NUM_RELAYS)
		return false;
	
	ESP_LOGI(TAG, "%sabling Relay %d (GPIO %d)", (enable?"En":"Dis"), num, relays_gpio_map[num]);

	gpio_set_level(relays_gpio_map[num], enable);

	return true;
}

static void handle_cmd(int sock, struct sockaddr_in6 *source_addr,
		       char *rx_buffer, unsigned int len)
{
	char addr_str[128];

	// Get the sender's ip address as string
	if (source_addr->sin6_family == PF_INET) {
		inet_ntoa_r(((struct sockaddr_in *)source_addr)->sin_addr.s_addr, addr_str, sizeof(addr_str) - 1);
	} else if (source_addr->sin6_family == PF_INET6) {
		inet6_ntoa_r(source_addr->sin6_addr, addr_str, sizeof(addr_str) - 1);
	}

	ESP_LOGI(TAG, "Received %d bytes from %s:", len, addr_str);
	ESP_LOGI(TAG, "%s", rx_buffer);

	if (!strncmp(rx_buffer, "VERSION", 7)) {
		char reply[128];

		sprintf(reply, "TINYCI %s", IDF_VER);
		int err = sendto(sock, reply, strlen(reply)+1, 0, (struct sockaddr *)source_addr, sizeof(*source_addr));
		if (err < 0)
			ESP_LOGE(TAG, "Error occurred during sending: errno %d", errno);
		return;
	}

	if (!strncmp(rx_buffer, "PWR", 3) || !strncmp(rx_buffer, "OFF", 3)) {
		if (relay_ctrl(rx_buffer))
			reply_str(sock, source_addr, true);
		else
			reply_str(sock, source_addr, false);
	}
	else
		reply_str(sock, source_addr, false);
}

#define PORT 1234

static void udp_server_task(void *pvParameters)
{
    char rx_buffer[10];
    int addr_family = (int)pvParameters;
    int ip_protocol = 0;
    struct sockaddr_in6 dest_addr;

    while (1) {

        if (addr_family == AF_INET) {
            struct sockaddr_in *dest_addr_ip4 = (struct sockaddr_in *)&dest_addr;
            dest_addr_ip4->sin_addr.s_addr = htonl(INADDR_ANY);
            dest_addr_ip4->sin_family = AF_INET;
            dest_addr_ip4->sin_port = htons(PORT);
            ip_protocol = IPPROTO_IP;
        } else if (addr_family == AF_INET6) {
            bzero(&dest_addr.sin6_addr.un, sizeof(dest_addr.sin6_addr.un));
            dest_addr.sin6_family = AF_INET6;
            dest_addr.sin6_port = htons(PORT);
            ip_protocol = IPPROTO_IPV6;
        }

        int sock = socket(addr_family, SOCK_DGRAM, ip_protocol);
        if (sock < 0) {
            ESP_LOGE(TAG, "Unable to create socket: errno %d", errno);
            break;
        }

        int err = bind(sock, (struct sockaddr *)&dest_addr, sizeof(dest_addr));
        if (err < 0) {
            ESP_LOGE(TAG, "Socket unable to bind: errno %d", errno);
        }
        ESP_LOGI(TAG, "Socket bound, port %d", PORT);

        while (1) {

            struct sockaddr_in6 source_addr; // Large enough for both IPv4 or IPv6
            socklen_t socklen = sizeof(source_addr);
            int len = recvfrom(sock, rx_buffer, sizeof(rx_buffer) - 1, 0, (struct sockaddr *)&source_addr, &socklen);

            // Error occurred during receiving
            if (len < 0) {
                ESP_LOGE(TAG, "recvfrom failed: errno %d", errno);
                break;
            }
            // Data received
            else {

                rx_buffer[len] = 0; // Null-terminate whatever we received and treat like a string...

		handle_cmd(sock, &source_addr, rx_buffer, len);
            }
        }

        if (sock != -1) {
            ESP_LOGE(TAG, "Shutting down socket and restarting...");
            shutdown(sock, 0);
            close(sock);
        }
    }
    vTaskDelete(NULL);
}

void app_main(void)
{
    int i;
    // Setup Relays GPIO
    gpio_config_t io_conf;
    //disable interrupt
    io_conf.intr_type = GPIO_INTR_DISABLE;
    //set as output mode
    io_conf.mode = GPIO_MODE_OUTPUT;
    //bit mask of the pins that you want to set,e.g.GPIO18/19
    io_conf.pin_bit_mask = 0;
    for (i = 0 ; i < 4/*NUM_RELAYS*/ ; ++i)
	io_conf.pin_bit_mask |= 1 << relays_gpio_map[i];
    //disable pull-down mode
    io_conf.pull_down_en = 0;
    //disable pull-up mode
    io_conf.pull_up_en = 0;
    //configure GPIO with the given settings
    gpio_config(&io_conf);

    // Initialize TCP/IP network interface aka the esp-netif (should be called only once in application)
    ESP_ERROR_CHECK(esp_netif_init());
    // Create default event loop that running in background
    ESP_ERROR_CHECK(esp_event_loop_create_default());

    esp_netif_config_t cfg = ESP_NETIF_DEFAULT_ETH();
    esp_netif_t *eth_netif = esp_netif_new(&cfg);

    // Register user defined event handers
    ESP_ERROR_CHECK(esp_event_handler_register(ETH_EVENT, ESP_EVENT_ANY_ID, &eth_event_handler, NULL));
    ESP_ERROR_CHECK(esp_event_handler_register(IP_EVENT, IP_EVENT_ETH_GOT_IP, &got_ip_event_handler, NULL));

    eth_mac_config_t mac_config = ETH_MAC_DEFAULT_CONFIG();
    eth_phy_config_t phy_config = ETH_PHY_DEFAULT_CONFIG();

    eth_esp32_emac_config_t esp32_emac_config = ETH_ESP32_EMAC_DEFAULT_CONFIG();

    phy_config.phy_addr = ETH_PHY_ADDR;
    phy_config.reset_gpio_num = ETH_PHY_RST_GPIO;

    esp32_emac_config.smi_mdc_gpio_num = ETH_MDC_GPIO;
    esp32_emac_config.smi_mdio_gpio_num = ETH_MDIO_GPIO;

    esp_eth_mac_t *mac = esp_eth_mac_new_esp32(&esp32_emac_config, &mac_config);
    esp_eth_phy_t *phy = esp_eth_phy_new_lan87xx(&phy_config);
    esp_eth_config_t config = ETH_DEFAULT_CONFIG(mac, phy);
    esp_eth_handle_t eth_handle = NULL;
    ESP_ERROR_CHECK(esp_eth_driver_install(&config, &eth_handle));
    /* attach Ethernet driver to TCP/IP stack */
    ESP_ERROR_CHECK(esp_netif_attach(eth_netif, esp_eth_new_netif_glue(eth_handle)));
    /* start Ethernet driver state machine */
    ESP_ERROR_CHECK(esp_eth_start(eth_handle));

    xTaskCreate(udp_server_task, "udp_server", 4096, (void*)AF_INET6, 5, NULL);
}

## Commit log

2020-11-18 Add v0.4 of tinicy-main and v0.1 of tiny-usb
    [prices.ods, tinyci-main.kicad_pcb, tinyci-main.sch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]
2020-11-18 Version v0.5
    [tinyci-main.kicad_pcb, tinyci-main.sch]
2020-11-18 fixup! Version v0.5
    [tinyci-main.kicad_pcb]
2020-11-18 fixup! fixup! Version v0.5
    [tinyci-main.kicad_pcb]
2020-11-18 TinyCI USB v0.1
    [tinyci-usb.kicad_pcb, tinyci-usb.sch]
2020-11-18 Add LICENCE to TinyCI-main
    [tinyci-main.kicad_pcb, tinyci-main.sch]
2020-11-18 Add LICENCE to TinyCI-USB
    [tinyci-usb.kicad_pcb, tinyci-usb.sch]
2020-11-23 Update prices with aliexpress commands & refs
    [prices.ods]
2020-12-01 Ordered Version !
    [tinyci-main.kicad_pcb, tinyci-usb.kicad_pcb]
2021-01-08 TinyCI USB 0.2
    - Updated schematic with correct USB Type A footprint
    - Fixed bad relay output (outputs must be disabled by default, activating the relay will send power to outputs)
    - removed LDO
    - added DC-DC screw terminal footprint + drawing of LM2596 DC-DC module to solder
    - grow mounting hole to 3.2mm to target M3 screws
    - relay 4 was missing Vinput signal to pin 1
    [tinyci-usb.kicad_pcb, tinyci-usb.sch]
2021-01-08 TinyCI 0.6
    - removed "5v-12v" text, this board will be 5V only, LDO heats too much at 12V
    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
    [tinyci-main.kicad_pcb, tinyci-main.sch]
2021-09-03 Add tinyci-relay.py
2021-09-03 Fixup tinyci-relay.py for python3
2021-11-19 TinyCI Main v0.7
    Remove post-relay protections, and move 1000uF caps before relay.
    Add proper OSHW & Made with KiCad logo
    [tinyci-main.kicad_pcb, tinyci-main.sch]
2021-11-19 TinyCI USB 0.3
    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
    [tinyci-usb.kicad_pcb, tinyci-usb.sch]
2021-11-19 Introduce TinySerial v1
    FT4232 quad uart board with 40pin header for all I/Os
    with same form factor as TinyCI.
    Also has holes to hook a Pi/LaFrite/LePotato to control the board
    and eventually some TinyCi USB relays.
    [tinyserial.kicad_pcb, tinyserial.sch]
2022-11-11 firmware: tinyci-relay: remove unused import
    Some import are useless, remove them.
2022-11-11 firmware: tinyci-relay: add a shebang
    Add missing shebang
2022-12-01 tinyci-main: Converted project and schematic to KiCad 6.
    Had to replace C1 and C3 capacitors symbol because it has been renamed in KiCad 6.
    [tinyci-main.kicad_sch, tinyci-main.sch]
2022-12-01 tinyci-main: Converted PCB to KiCad 6.
    [tinyci-main.kicad_pcb]
2022-12-01 tinyci-main: Added stacked USB-A connectors to schematic so they are easier to route.
    [USB_Connectors.kicad_sch, tinyci-main.kicad_sch]
2022-12-01 tinyci-main: Replaced the PCB single USB-A connectors by the stacked ones.
    [tinyci-main.kicad_pcb]
2022-12-02 tinyci-main: Bumped version to 0.8.
    [USB_Connectors.kicad_sch, tinyci-main.kicad_pcb, tinyci-main.kicad_sch]
2023-01-09 tinyci-relay: need to import sys
    My cleaning via f256e9216f3e ("firmware: tinyci-relay: remove unused import") was too much, I removed sys when I should not.
2023-02-15 tinyci-main: Replaced the relay coil flyback diodes by SMD parts to speed up the board assembly.
    [tinyci-main.kicad_pcb, tinyci-main.kicad_sch]
2023-02-15 tinyci-main: Replaced the relay coil transistors by SMD parts to speed up the board assembly.
    [tinyci-main.kicad_pcb, tinyci-main.kicad_sch]
2023-02-15 tinyci-main: Bumped version to 0.9.
    [USB_Connectors.kicad_sch, tinyci-main.kicad_pcb, tinyci-main.kicad_sch]

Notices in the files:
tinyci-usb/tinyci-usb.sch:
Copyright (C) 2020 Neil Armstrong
